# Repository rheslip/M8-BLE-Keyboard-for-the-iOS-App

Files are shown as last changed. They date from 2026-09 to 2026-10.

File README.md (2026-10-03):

**BLE Wireless Keyboard for the M8 iOS App**

When I saw that Dirtywave had released an M8 app on iOS one my first thoughts was to make an M8 like keyboard for it. I have an M8 headless that is almost identical to the real M8 and I wanted to leverage the muscle memory I had developed for that.

Altho it was created for use with the iOS app, with some software modifications it would work on a PC with the M8 Headless as well.

Oct 3/2026 - more or less final version of the code which shows battery levels on the RGB LED

Sept 17/2026 - added hardware design files for PCB and two enclosure variants (AAA battery and LiPo with charging jack) - tested and working OK

Video demo of the final version https://www.youtube.com/watch?v=-Xh-XhrWJC8&t=2s

The prototype worked very well so I have designed a PCB and enclosure which more or less duplicates the M8 V1 design - eight Kailh switches, approx 97mm x 84mm x18mm, white silkscreen. It has a small RGB led for indicating battery status, pads for a switch and pads for a lipo charger module as well.

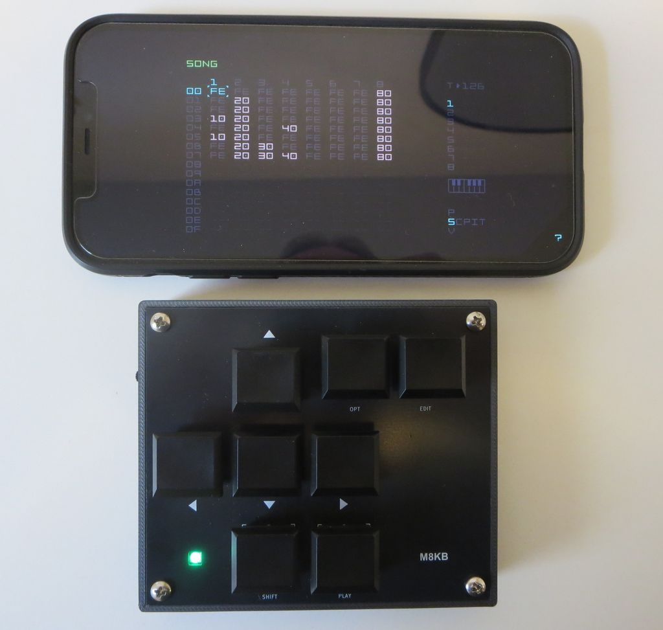
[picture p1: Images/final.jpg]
M8KB
  
 
M8 V1 and V2 images for reference

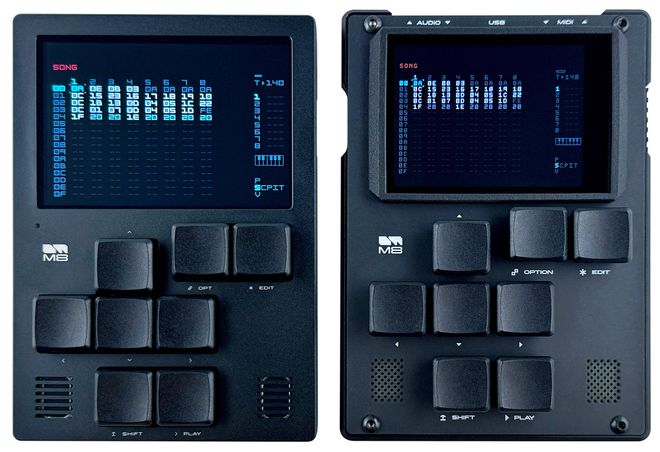
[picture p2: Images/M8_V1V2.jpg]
M8 Version 2 and 1
 
 
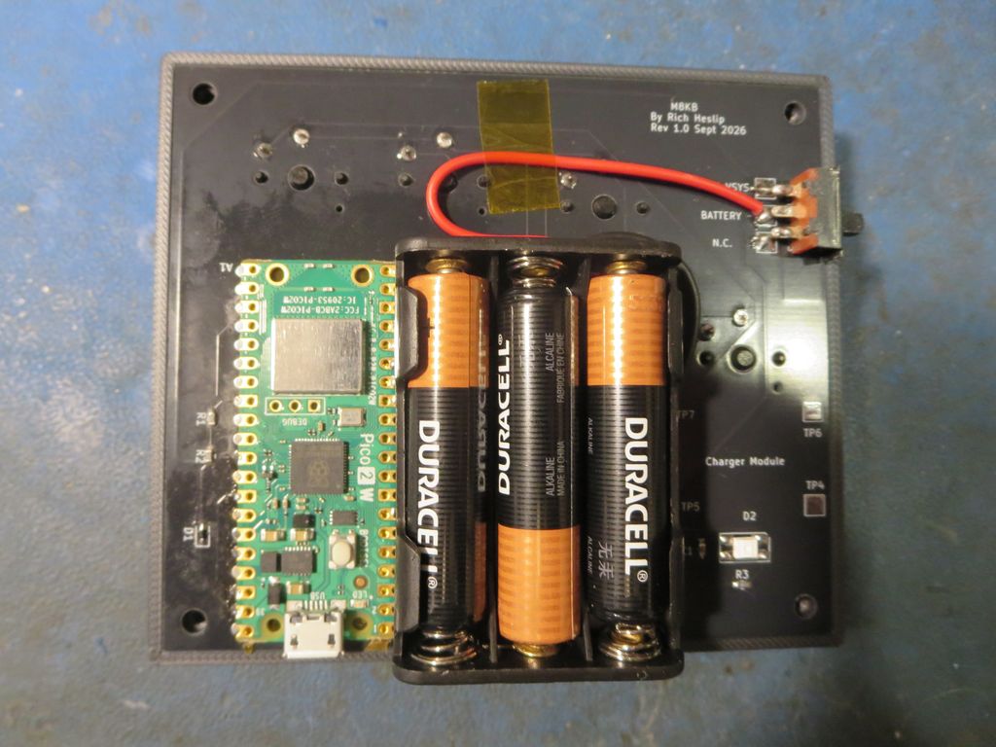
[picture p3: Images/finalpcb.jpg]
Component side of PCB with AAA batteries
  
 
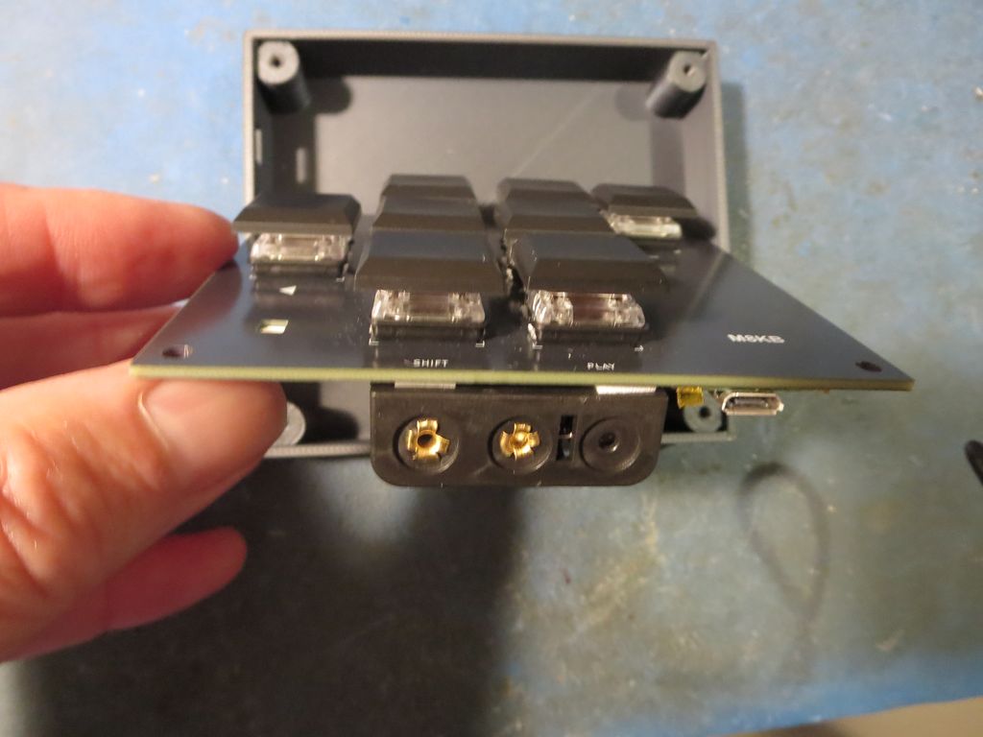
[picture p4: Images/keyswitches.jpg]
Kailh Switches
  
 
PCB images:

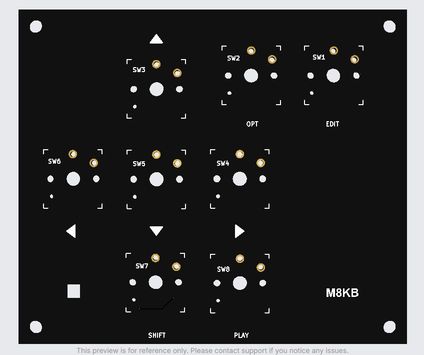
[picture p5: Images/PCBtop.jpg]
M8KB PCB front side
 
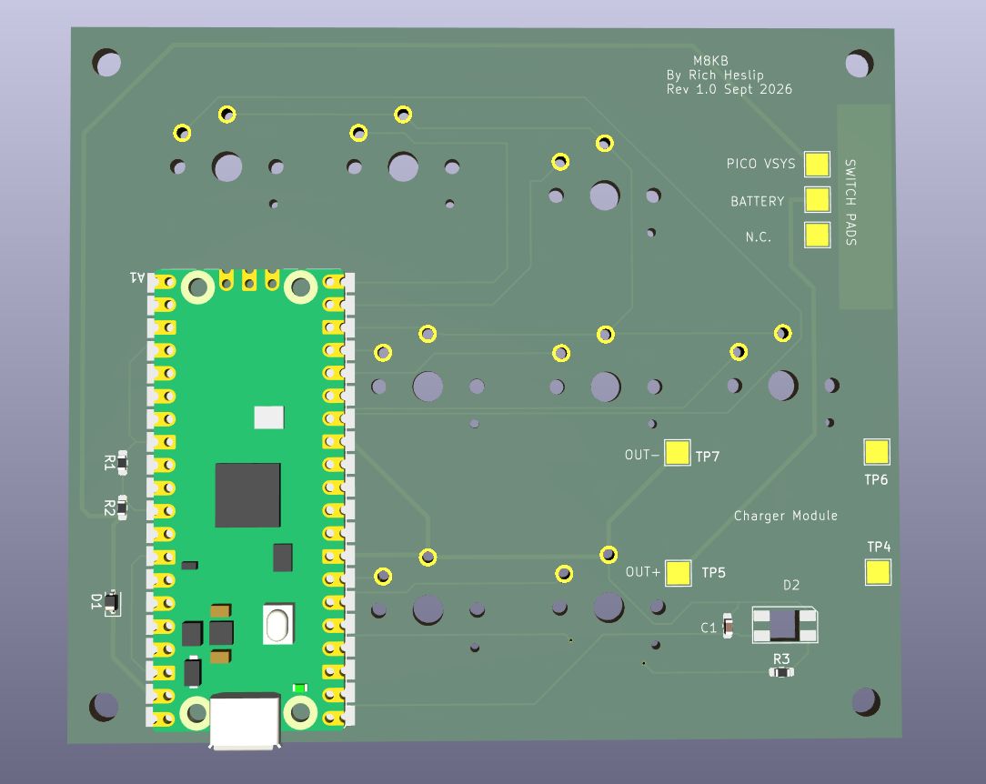
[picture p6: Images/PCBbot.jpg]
M8KB PCB back side
  
 
 You may notice there is no ground fill on the board. This is intentional - a large GND plane near the antenna will mess with the BLE signal. I also wanted a clean front panel with no visible planes/traces/vias.
 
 3D Renders of the enclosure. Note the cutouts for USB-C charging jack and switch on the LiPo version. A version with no USB jack is provided for use with a AAA battery holder. 

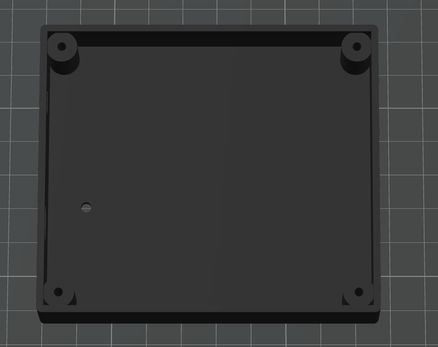
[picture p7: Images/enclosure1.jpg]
Front view
  
 
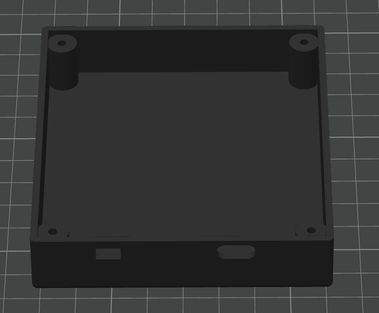
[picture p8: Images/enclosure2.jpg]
Side view
   

Batteries

I use LiPo batteries and small charger modules from AliExpress. The PCB footprint is for this one which has a LiPo protection circuit as well but you can barnacle almost any of these on and make it work.

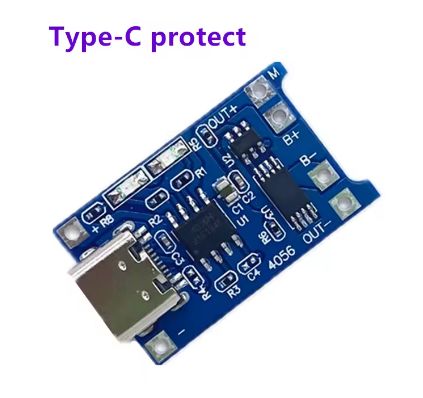
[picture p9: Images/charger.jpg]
charger
 

**CAUTION this TP4056 charger module is set up for 1A charge rate which is too high for most small LiPo's** 
To be safe you will want to change the current setting resistor to something like 1/3 of the battery capacity.

**LiPo batteries are a fire hazard!!! Do not use a LiPo unless you are comfortable modifying the module appropriately, testing it, and are willing to take the risk**

Alternatively use 3 AAA batteries which is much safer. You can use 2x AAA as well but the battery life will be reduced by 1/3.
The battery indicator is set up for the range of a LiPo 4.2V full, 3V cutoff which is about the same voltage range as three AAA. If you use something else you will need to modify the sketch.

Power consumption of the Pico 2 W running this sketch is around 40ma at 5V (0.2 watts). If you use three AAA alkalines (around 3WH) the batteries should last around 15 hours. An 800 Mah LiPo should have about the same battery life.
Unfortunately the Pico 2 BLE stack does not support power management or underclocking which would have been nice to extend the battery life.

Usage

I have not had much luck getting the iOS bluetooth settings to see the M8KB device directly. Adafruit's Bluefruit Connect app sees it and pairs with it no problem. After pairing with Bluefruit Connect, iOS will automatically connect to it every time. This is not the first time I've have trouble with bluetooth devices on iOS. There seem to be some subtle incompatibilies between the Pico's implementation of BLE and what Apple wants to see.

If you recompile and reinstall the firmware you have to forget the device and pair it again on your iPad/iPhone. 

The default key bindings are set up to work with the M8 app default keyboard assignment but you may have to re-bind the key assignments in the M8 app to get everything working correctly. In particular the M8 app sees the SHIFT and EDIT keys as the same key until you re-bind them. I think this is because the Arduino keyboard library treats the shift key as a modifier and not as a separate key. You will only have to do this once - the M8 app remembers the key bindings.

Another oddity is that if you are using the M8 app in AUM when you switch to another AUV3 plugin and come back to M8 it loses the connection to M8KB. You can restore it by double tapping the screen to hide/show the on screen controls. M8KB does not show up in the device list in AUM either but it works OK other than the aforementioned disconnect. More weirdness with Pico + iOS BLE or perhaps a bug in the M8 app. 

It connects to a PC but doesn't work with M8 web display. It would probably work by changing the Pico library from keyboardBLE to gamepadBLE. More testing is needed.

Assembly

Solder the three 0603 resistors, the .1u cap and the schottky diode. Solder in the RGB LED making sure that the orientation matches the silkscreen and make sure the lens is facing the FRONT of the PCB. If you don't want to source this LED, you can barnacle an SMT LED or even a 3mm LED to the pads but you will have to modify the sketch to make it blink or something when the battery is low.

Solder the Pico 2W to the pads. 
If you think you may want to remove it at some point best to use small wires or perhaps put some kapton tape on the bottom of the Pico - if the pads have been soldered directly to the PCB pads its very hard to desolder. Also make sure the USB connector edge is flush with the PCB edge - you don't want it to stick out because there is no provision for it in the enclosure. ie load the firmware with the board out of the enclosure.

Solder in the Kailh 1350 switches so the plungers are on the front side of the PCB (obviously). These switches are the same ones used on the M8 and they are available with different actuation forces and "clickiness". The M8 has removable switches - I had the sockets in the design and then took them out. M8 users probably already know which switches they like.

If you are using a LiPo, solder the charger module to the four pads so the USB jack faces to the left with the board switch side up. Solder the negative battery lead to the B- pad on the charger module. At this point its a very good idea to put a current meter between the B+ pad and the battery + lead - make sure the power switch is off. If everything is OK there should be just a very tiny leakage current. If not, you probably have a bad module. I always check the charging current at this stage as well.

If you are using a AAA holder, solder the +ve lead to the OUT+ pad and the -ve lead to OUT- pad. A 3x AAA battery holder should just fit between the Pico and the charger pads and can be stuck to the PCB with double sided foam tape. 

I couldn't find a suitable PCB mounted R/A slide switch so I went with PCB pads so you can solder in whatever you have. I use small slide switches about 5mm thick by 13mm wide. Glue it to the PCB and wire the switch leads to the provided pads. Make sure the switch is flush with the edge of the PCB and aligned with the switch cutout in the enclosure.

The mounting holes in the enclosure are sized for 4-40 or 3mm screws - tap the holes. You could also use small wood or plastic cutting screws.

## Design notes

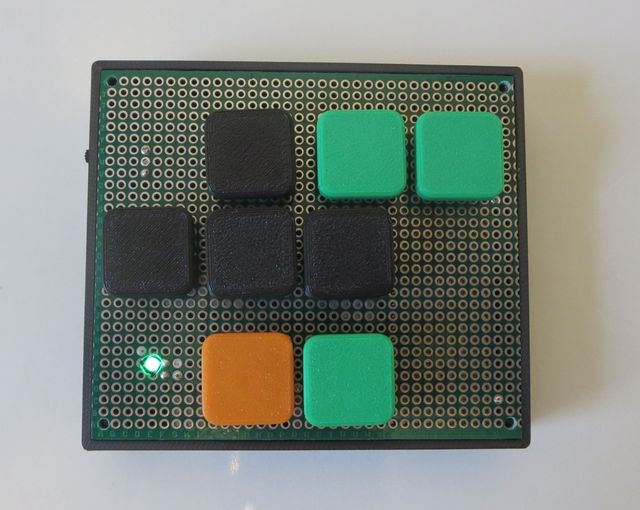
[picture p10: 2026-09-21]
Images/proto2.jpg

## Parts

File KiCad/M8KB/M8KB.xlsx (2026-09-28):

Reference | Qty | Value | Footprint | Notes | Link
A1 | 1 | RaspberryPi_Pico 2_W | MyLibrary:RaspberryPi_Pico_SMD | Pico W should work too
C1 | 1 | 0.1u | C_0603_1608
D1 | 1 | 1N5819WS | SOD-323 (Tiny !) | 1N4148 works with slight loss of efficiency
D2 | 1 | SK6812E-MINI | SK6812_MINI-E | https://www.aliexpress.com/item/1005005193716172.html?scm_id=1007.24625.271276.0&scm-url=1007.24625.271276.0
R1,R2 | 2 | 100k | R_0603_1608
R3 | 1 | 33R | R_0603_1608 | * can be used as a current limiter
SW1,SW2,SW3,SW4,SW5,SW6,SW7,SW8 | 8 | SW_Push | Kaihl 1350 | Available on Amazon or Aliexpress
 | 8 | Switch caps |  | ""
 |  | TP4056 Charger Module | optional - use with a Lipo | ** CAUTION | https://www.aliexpress.com/item/1005010336650584.html?curPageLogUid=pBeZdTSlz3KE
 |  | Switch caps | small slide switch
 |  | Battery Holder | 3 AAA
 |  |  |  | * if you can't find the SK6812 you can put an SMT LED from the DATA pad to GND - this resistor becomes the current limiter - 2.2k or so.
 |  |  |  | * this change will require mods to the sketch as well
 |  |  |  | ** these modules charge at 1A which is too high for small LiPo batteries
 |  |  |  | ** you MUST change the charge rate resistor

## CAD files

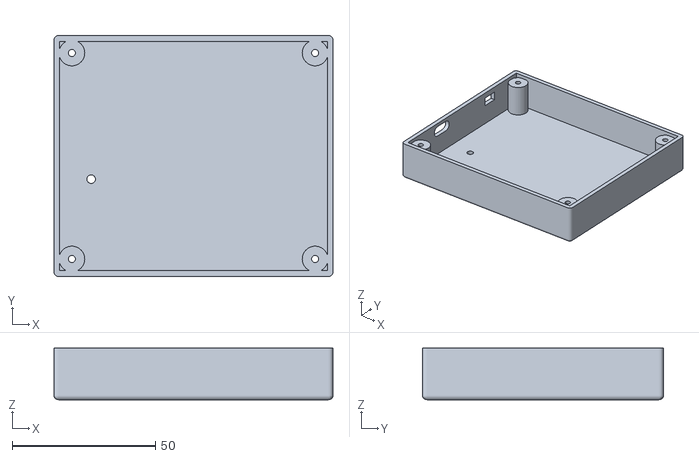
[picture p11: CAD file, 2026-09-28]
Enclosure/M8KB Enclosure Lipo.stl
97.5 x 84.2 x 18.0

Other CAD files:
Enclosure/M8KB Enclosure.stl

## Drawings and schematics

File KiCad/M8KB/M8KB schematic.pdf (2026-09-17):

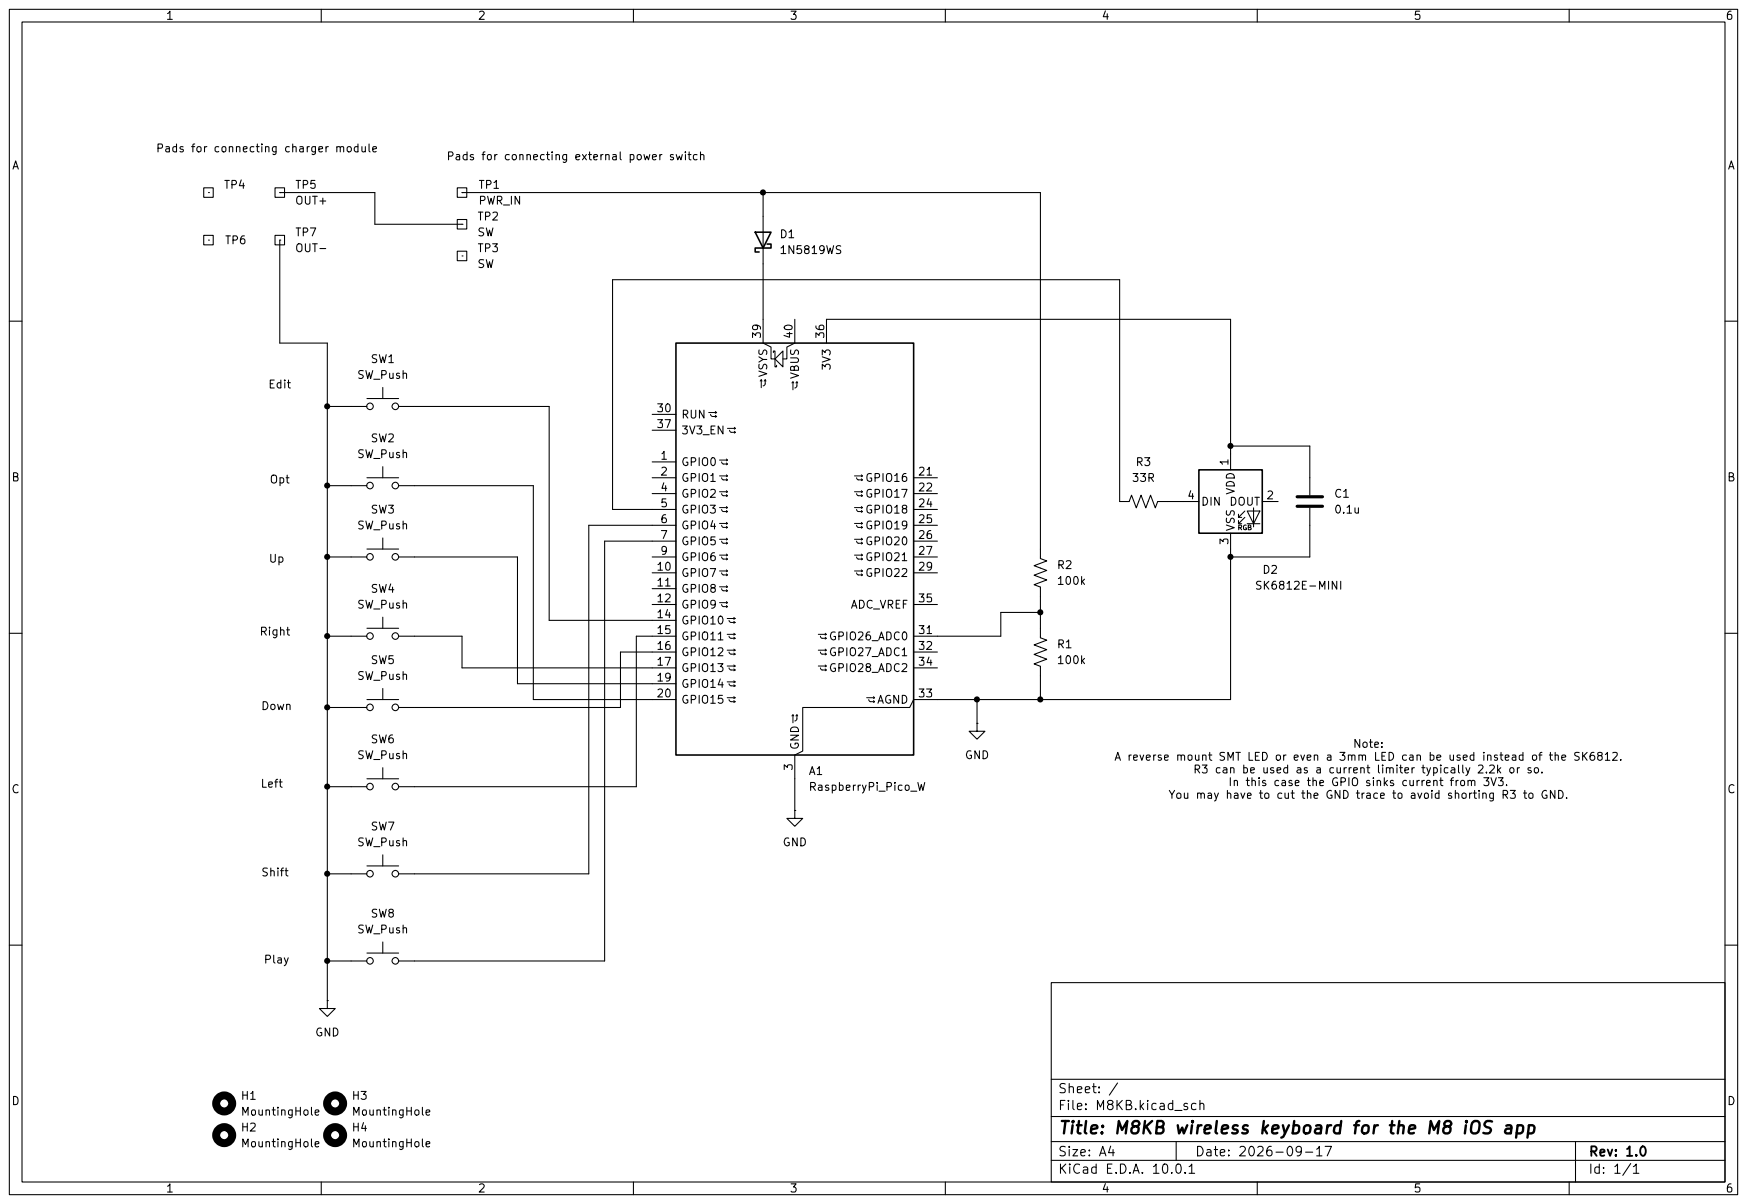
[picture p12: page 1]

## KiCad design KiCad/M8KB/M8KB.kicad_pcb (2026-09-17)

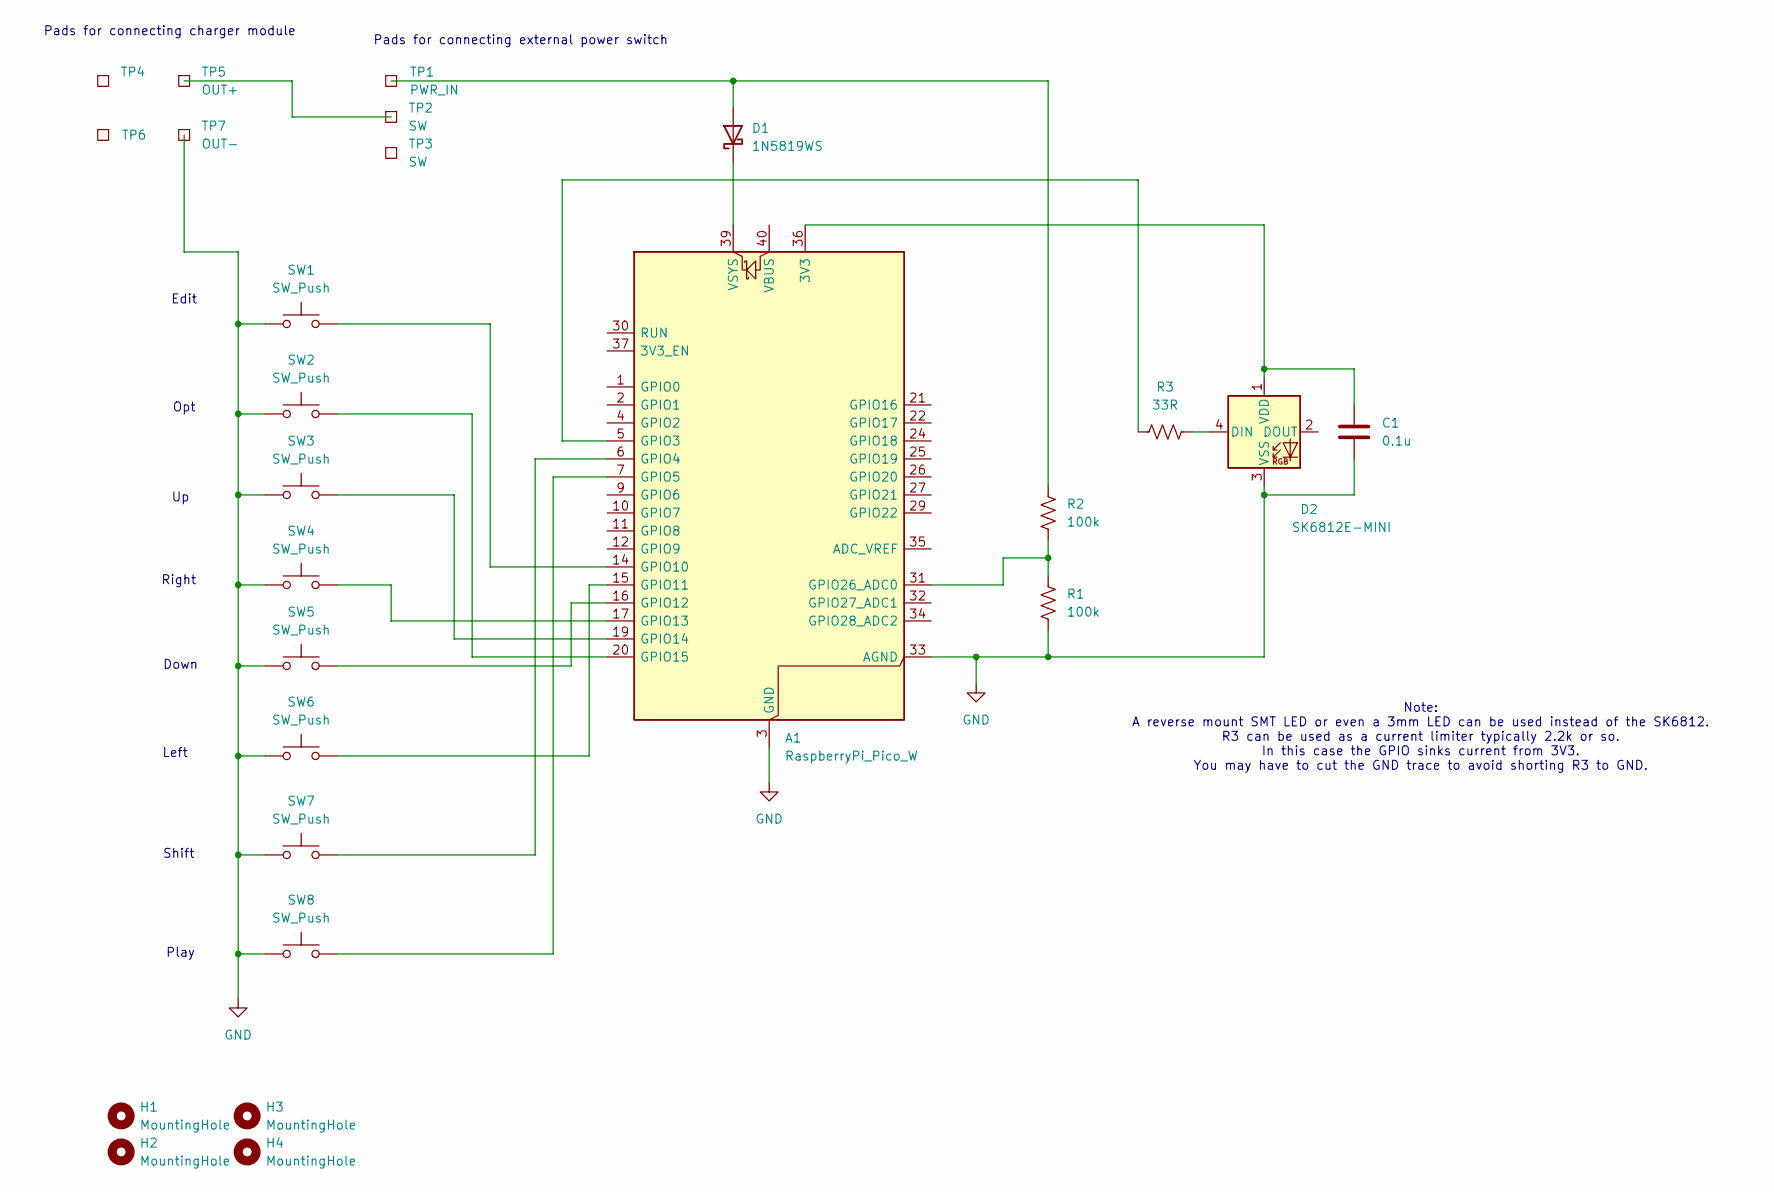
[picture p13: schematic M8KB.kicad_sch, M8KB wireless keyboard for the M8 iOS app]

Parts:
A1: RaspberryPi_Pico_W; RaspberryPi_Pico_SMD
C1: 0.1u; C_0603_1608Metric_Pad1.08x0.95mm_HandSolder
D1: 1N5819WS; D_SOD-323
D2: SK6812E-MINI; LED_OPSCO_SK6812_MINI-E_5.0x5.0mm_P3.1mm_rearmount
H1, H2, H3, H4: MountingHole; MountingHole_3.2mm_M3_ISO14580
R1, R2: 100k; R_0603_1608Metric_Pad0.98x0.95mm_HandSolder
R3: 33R; R_0603_1608Metric_Pad0.98x0.95mm_HandSolder
SW1, SW2, SW3, SW4, SW5, SW6, SW7, SW8: SW_Push; SW_PG1350
TP1: PWR_IN; TestPoint_Pad_2.5x2.5mm
TP2, TP3: SW; TestPoint_Pad_2.5x2.5mm
TP4, TP6: TestPoint_Pad_2.5x2.5mm
TP5: OUT+; TestPoint_Pad_2.5x2.5mm
TP7: OUT-; TestPoint_Pad_2.5x2.5mm

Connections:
GND: A1.3 (GND), A1.8 (GND), A1.13 (GND), A1.18 (GND), A1.23 (GND), A1.28 (GND), A1.33 (AGND), A1.38 (GND), C1.2, D2.3 (VSS), R1.2, SW1.1, SW2.1, SW3.1, SW4.1, SW5.1, SW6.1, SW7.1, SW8.1, TP7.1 (1_1)
unnamed: A1.36 (3V3), C1.1, D2.1 (VDD)
unnamed: A1.5 (GPIO3), R3.1
unnamed: A1.6 (GPIO4), SW7.2
unnamed: A1.7 (GPIO5), SW8.2
unnamed: A1.14 (GPIO10), SW1.2
unnamed: A1.15 (GPIO11), SW6.2
unnamed: A1.16 (GPIO12), SW5.2
unnamed: A1.17 (GPIO13), SW4.2
unnamed: A1.19 (GPIO14), SW3.2
unnamed: A1.20 (GPIO15), SW2.2
unnamed: A1.31 (GPIO26_ADC0), R1.1, R2.2
unnamed: A1.39 (VSYS), D1.1 (K)
unnamed: D1.2 (A), R2.1, TP1.1 (1_1)
unnamed: D2.4 (DIN), R3.2
unnamed: TP2.1 (1_1), TP5.1 (1_1)

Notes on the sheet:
Play
Shift
Left
Note: A reverse mount SMT LED or even a 3mm LED can be used instead of the SK6812. R3 can be used as a current limiter typically 2.2k or so. In this case the GPIO sinks current from 3V3. You may have to cut the GND trace to avoid shorting R3 to GND.
Down
Edit
Pads for connecting charger module
Pads for connecting external power switch
Right
Opt

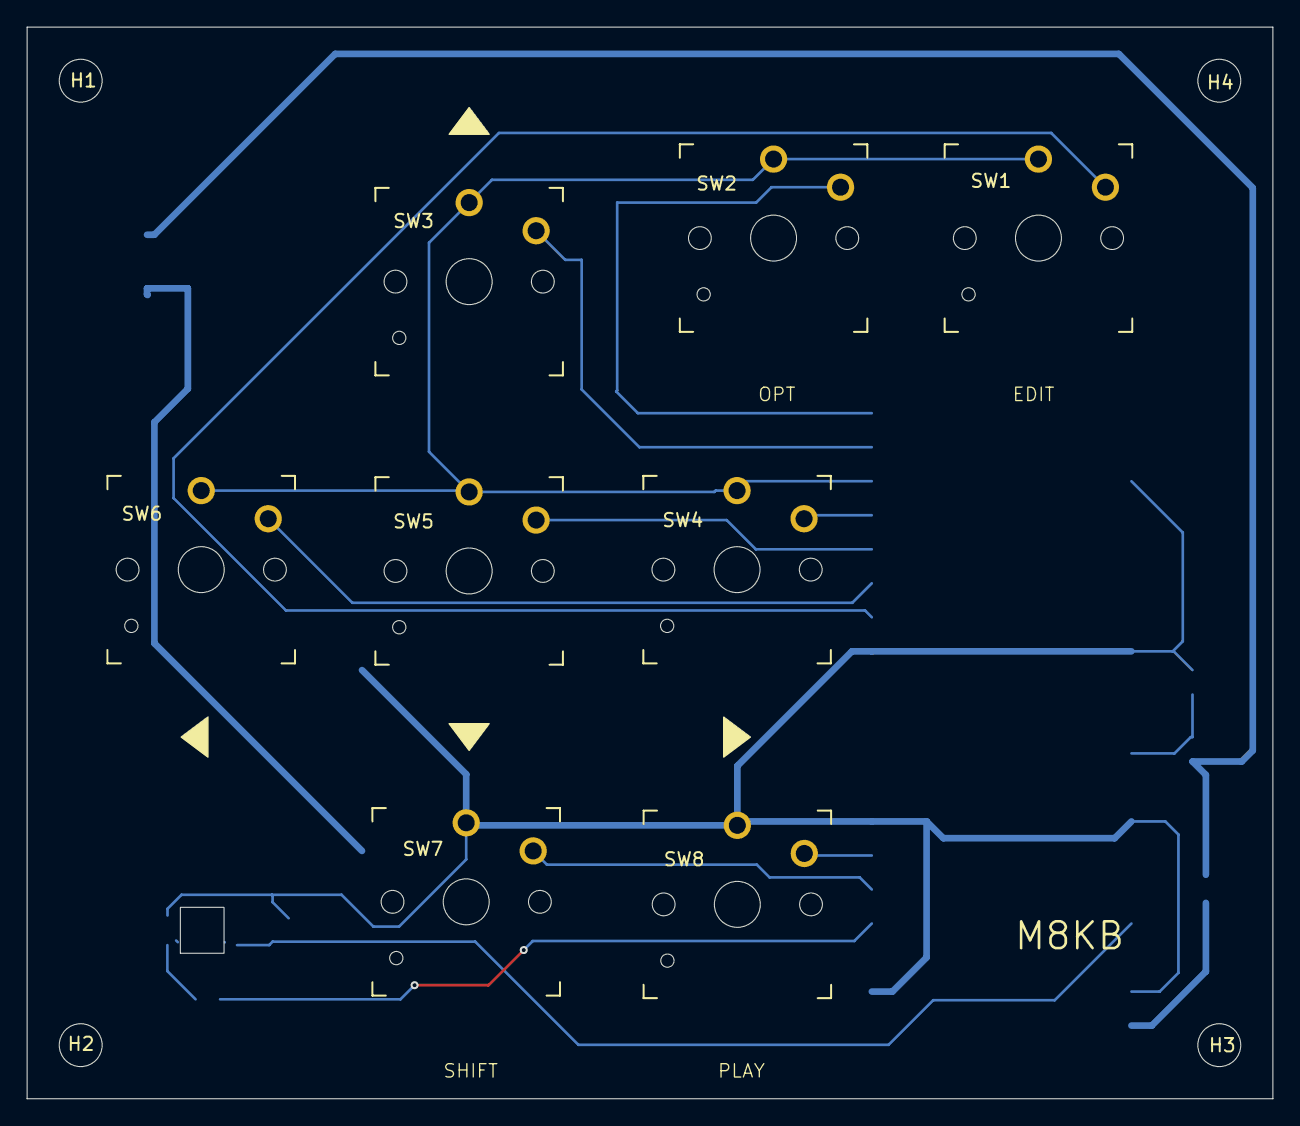
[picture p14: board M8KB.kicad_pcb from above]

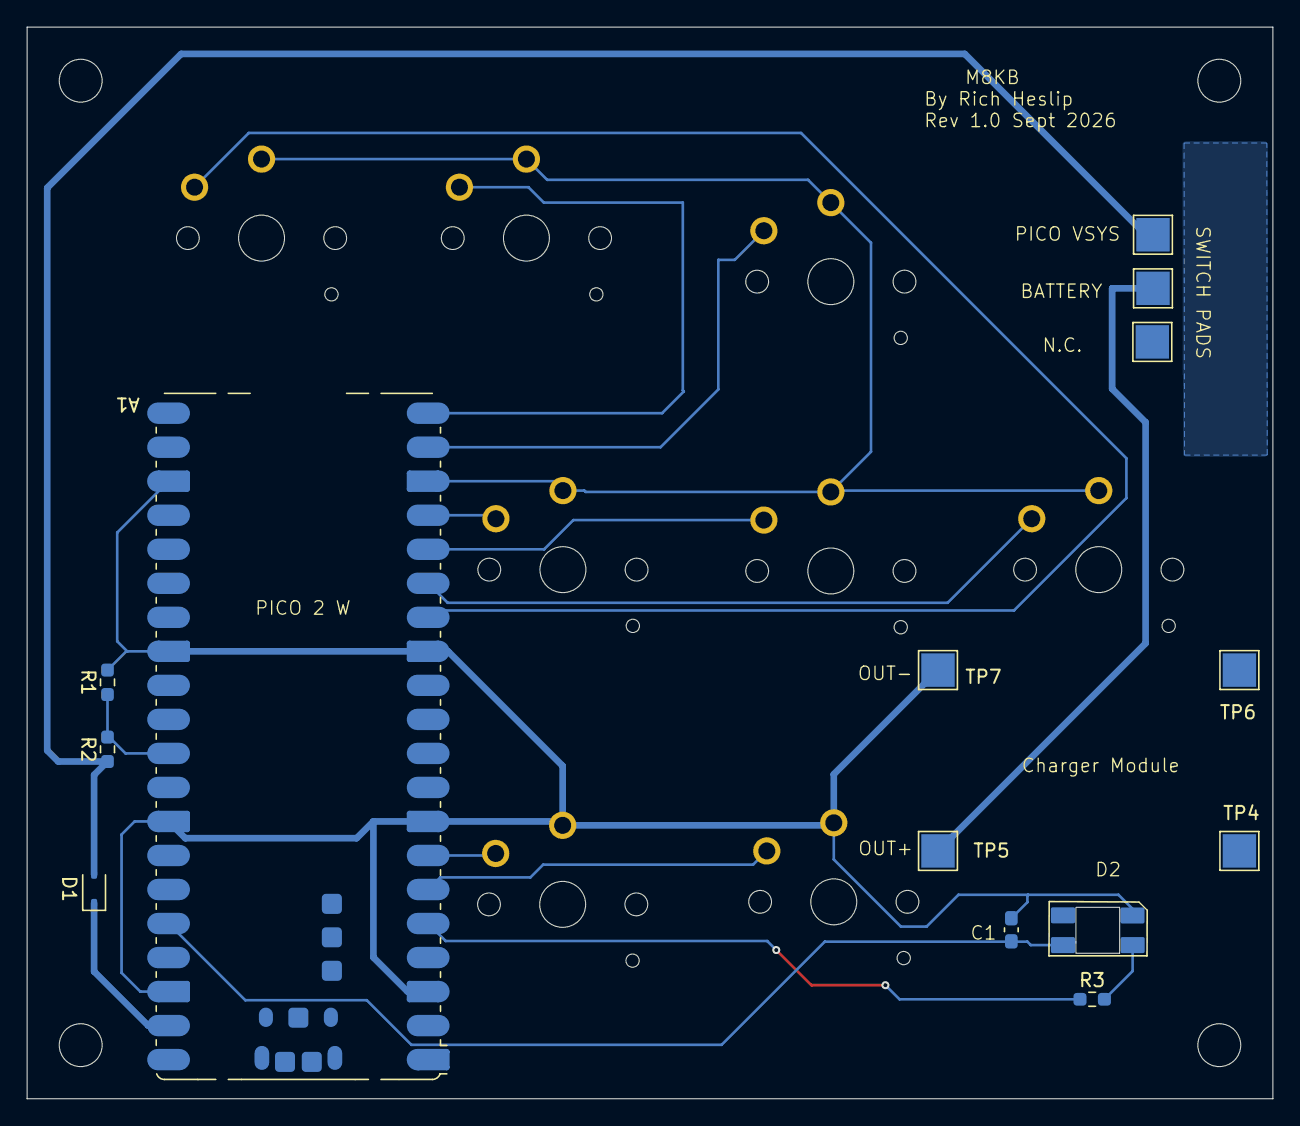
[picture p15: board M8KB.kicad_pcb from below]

Board: 2 copper layers, 93.0 x 80.0 mm, 26 parts (14 on the bottom side), 16 nets.

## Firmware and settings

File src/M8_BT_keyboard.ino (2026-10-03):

/*
// Copyright (c) 2026, Rich Heslip
//
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
BLE keyboard using Raspberry Pi Pico 2 for the M8 iOS app

Sept 15/2026 - first drop of the code for the prototype HW. 

based on example code by Tom Igoe:

  https://www.arduino.cc/en/Tutorial/BuiltInExamples/KeyboardSerial
*/

//#include <BLE.h>
#include <KeyboardBLE.h>
#include <Adafruit_NeoPixel.h>

//BLEDevice central = BLE.central();

#define KEYSCANTIME 5  // delay between key scans for debounce
#define DEBOUNCECOUNT 4 //  number of keyscan delays for debounce

#define NUMKEYS 8

// GPIOs that sense key closures to GND
#define EDITKEY 10
#define OPTKEY 15
#define UPKEY 14
#define RIGHTKEY 13
#define DOWNKEY 12
#define LEFTKEY 11
#define SHIFTKEY 4
#define PLAYKEY 5

int8_t keyGPIO [8]= {EDITKEY,OPTKEY,UPKEY,RIGHTKEY,DOWNKEY,LEFTKEY,SHIFTKEY,PLAYKEY}; // key index 0-7 to key GPIO mapping

#define LEDPIN 3
#define NUMPIXELS 1 // 
#define LEDFLASH 100
#define LED_RED 0x030000  // only using 2 bits to keep LEDs from getting too bright and to save power
#define LED_GREEN 0x000300
#define LED_BLUE 0x000003
#define LED_OFF 0
// battery level colors from red to green
#define BATTCOLORS 4
int32_t battcolors[]={LED_RED,0x020000+0x000100,0x010000+0x000200,LED_GREEN};

Adafruit_NeoPixel LED(NUMPIXELS, LEDPIN, NEO_GRB + NEO_KHZ800);

#define BATTERYVOLTAGEINTERNAL 29  // internal connection on Pico W 2
#define BATTERYVOLTAGE 26  // external resistor divider connection
// bat voltage ranges for LiPo
//#define BATOK 560  // approx 3.6v - bat voltage read thru external 2:1 divider
//#define BATLOW 500 // approx 3.2v
// bat voltage ranges for 3x AAA batteries
#define BATOK 580  // approx 3.75v - bat voltage read thru external 2:1 divider
#define BATLOW 450 // approx 3 v
#define BATTSAMPLE 1000 // timer period for battery sampling. don't want to update the RGB LED too often because it could cause issues with the BLE signal

void BLE_flash(void) {
  LED.setPixelColor(0,LED_BLUE); 
  LED.show();
  delay(LEDFLASH);
  LED.setPixelColor(0,LED_OFF); 
  LED.show();
  delay(LEDFLASH);
}

void showbatterylevel(void) { 
  int16_t batvoltage=analogRead(BATTERYVOLTAGE);
//  Serial.printf("bat = %d\n",batvoltage);
  batvoltage=constrain(batvoltage,BATLOW,BATOK);
  LED.setPixelColor(0,battcolors[map(batvoltage,BATLOW,BATOK,0,BATTCOLORS-1)]); 
  LED.show();
}

void setup() {
  Serial.begin(115200);
  for (uint8_t i=0;i<NUMKEYS;++i) pinMode(keyGPIO[i],INPUT_PULLUP); 

  LED.begin(); // INITIALIZE NeoPixel strip object (REQUIRED)
  showbatterylevel();
  KeyboardBLE.begin();
//  while (!central.connected()) BLE_flash(); // so far I can't figure out how to detect BLE connection status
}

void loop() {
  static uint16_t keymap=0;
  static uint16_t keycnt=0;
  static uint32_t batt_timer;
  static int16_t scancnt;
  bool keystate;


  for (uint8_t i=0;i<NUMKEYS;++i)  {
    keystate=!digitalRead(keyGPIO[i]);  // read key 
    if ((bool)(keymap & (1<<i)) != keystate) { // if its different than last scan
      if (keycnt > DEBOUNCECOUNT ) {  // debounce
        if (keystate) keymap|=1 <<i;  // debounced, update state
        else keymap &= 0xfe << i;

        switch (i) {  // process key up and down
          case 0:  // edit key
            if (keystate) KeyboardBLE.press('X');
            else KeyboardBLE.release('X');
            break;
          case 1: // OPT key
            if (keystate) KeyboardBLE.press('Z');
            else KeyboardBLE.release('Z');
            break;
          case 2: // UP key
            if (keystate) KeyboardBLE.press(KEY_UP_ARROW);
            else KeyboardBLE.release(KEY_UP_ARROW);
            break;
          case 3: // RIGHT key
            if (keystate) KeyboardBLE.press(KEY_RIGHT_ARROW);
            else KeyboardBLE.release(KEY_RIGHT_ARROW);
            break;
          case 4: // DOWN key
            if (keystate) KeyboardBLE.press(KEY_DOWN_ARROW);
            else KeyboardBLE.release(KEY_DOWN_ARROW);
            break;
          case 5: // LEFT key
            if (keystate) KeyboardBLE.press(KEY_LEFT_ARROW);
            else KeyboardBLE.release(KEY_LEFT_ARROW);
            break;
          case 6: // SHIFT key
            if (keystate) KeyboardBLE.press(KEY_RIGHT_SHIFT);  
            else KeyboardBLE.release(KEY_RIGHT_SHIFT);
            break;
          case 7:  // play key
            if (keystate) KeyboardBLE.press(' ');
            else KeyboardBLE.release(' ');
            break;       
        }
        delay(10); // We need a short delay here, sending packets with less than 1ms leads to packet loss!
      }
      else {
        ++keycnt;
        delay(1); // key bounce delay
      }
    }   
  }

  if ((millis()-batt_timer) > BATTSAMPLE) {
    batt_timer=millis();
    showbatterylevel();
  }
}

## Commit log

2026-09-17 Added PCB design files
    Added Kicad design files and images
    [M8KB.kicad_pcb, M8KB.kicad_sch]
2026-09-17 Added enclosure file
    [M8KB Enclosure.stl]
2026-09-17 added image of charger module
2026-09-21 Added image of 2nd prototype
2026-09-28 Updated enclosures, added BOM
    [M8KB Enclosure Lipo.stl, M8KB Enclosure.stl, M8KB.xlsx]
